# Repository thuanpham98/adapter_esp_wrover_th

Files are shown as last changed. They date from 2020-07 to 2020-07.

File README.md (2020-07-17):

# ESP-WROVER_OPEN
## Hardware

### PCB Layout

#### Dismention 
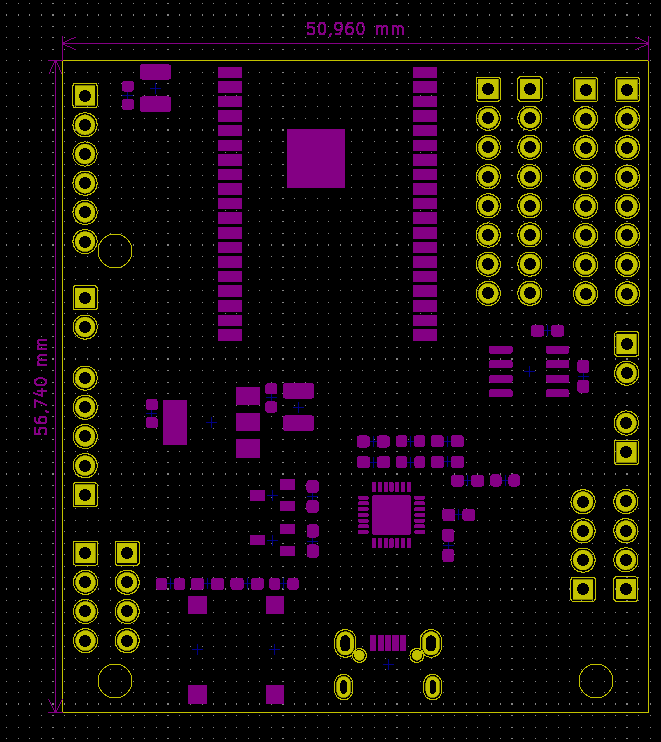
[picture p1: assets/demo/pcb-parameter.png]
pcb-parameter


#### Top side 

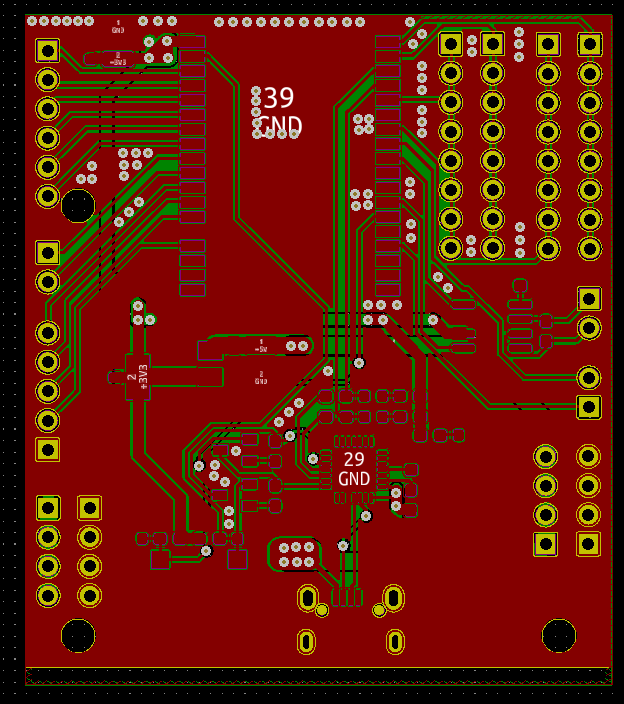
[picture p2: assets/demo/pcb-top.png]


#### Back side 

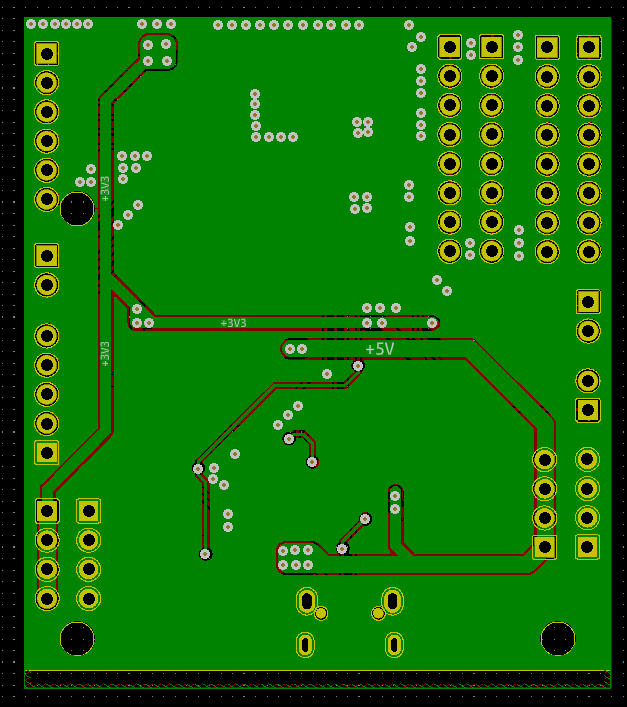
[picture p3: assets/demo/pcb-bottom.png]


### 3D

#### Top side 

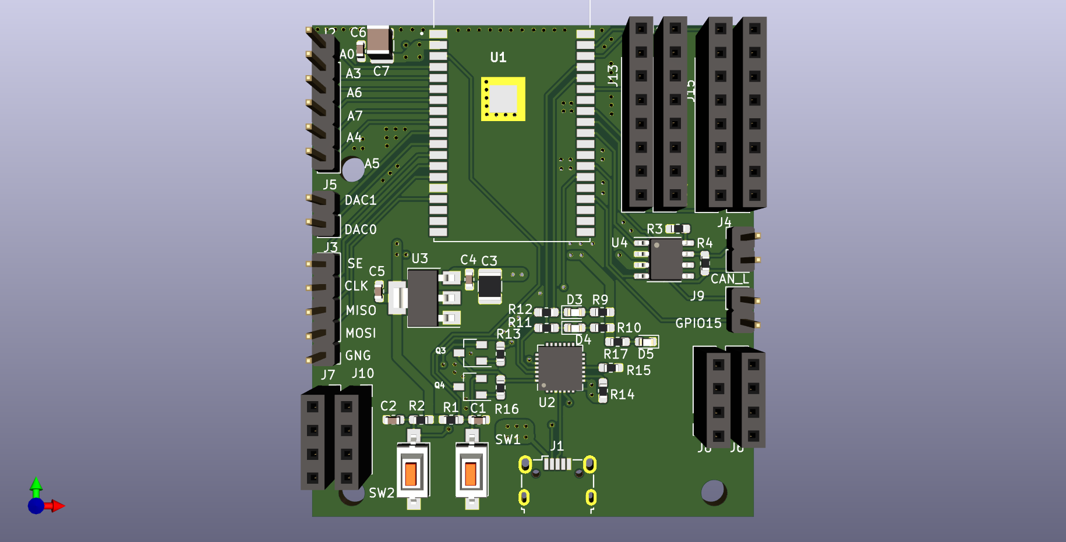
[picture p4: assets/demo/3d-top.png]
BE-AMP 3D REVIEW


#### Back side 

BE-AMP 3D REVIEW

### Gerber

# License

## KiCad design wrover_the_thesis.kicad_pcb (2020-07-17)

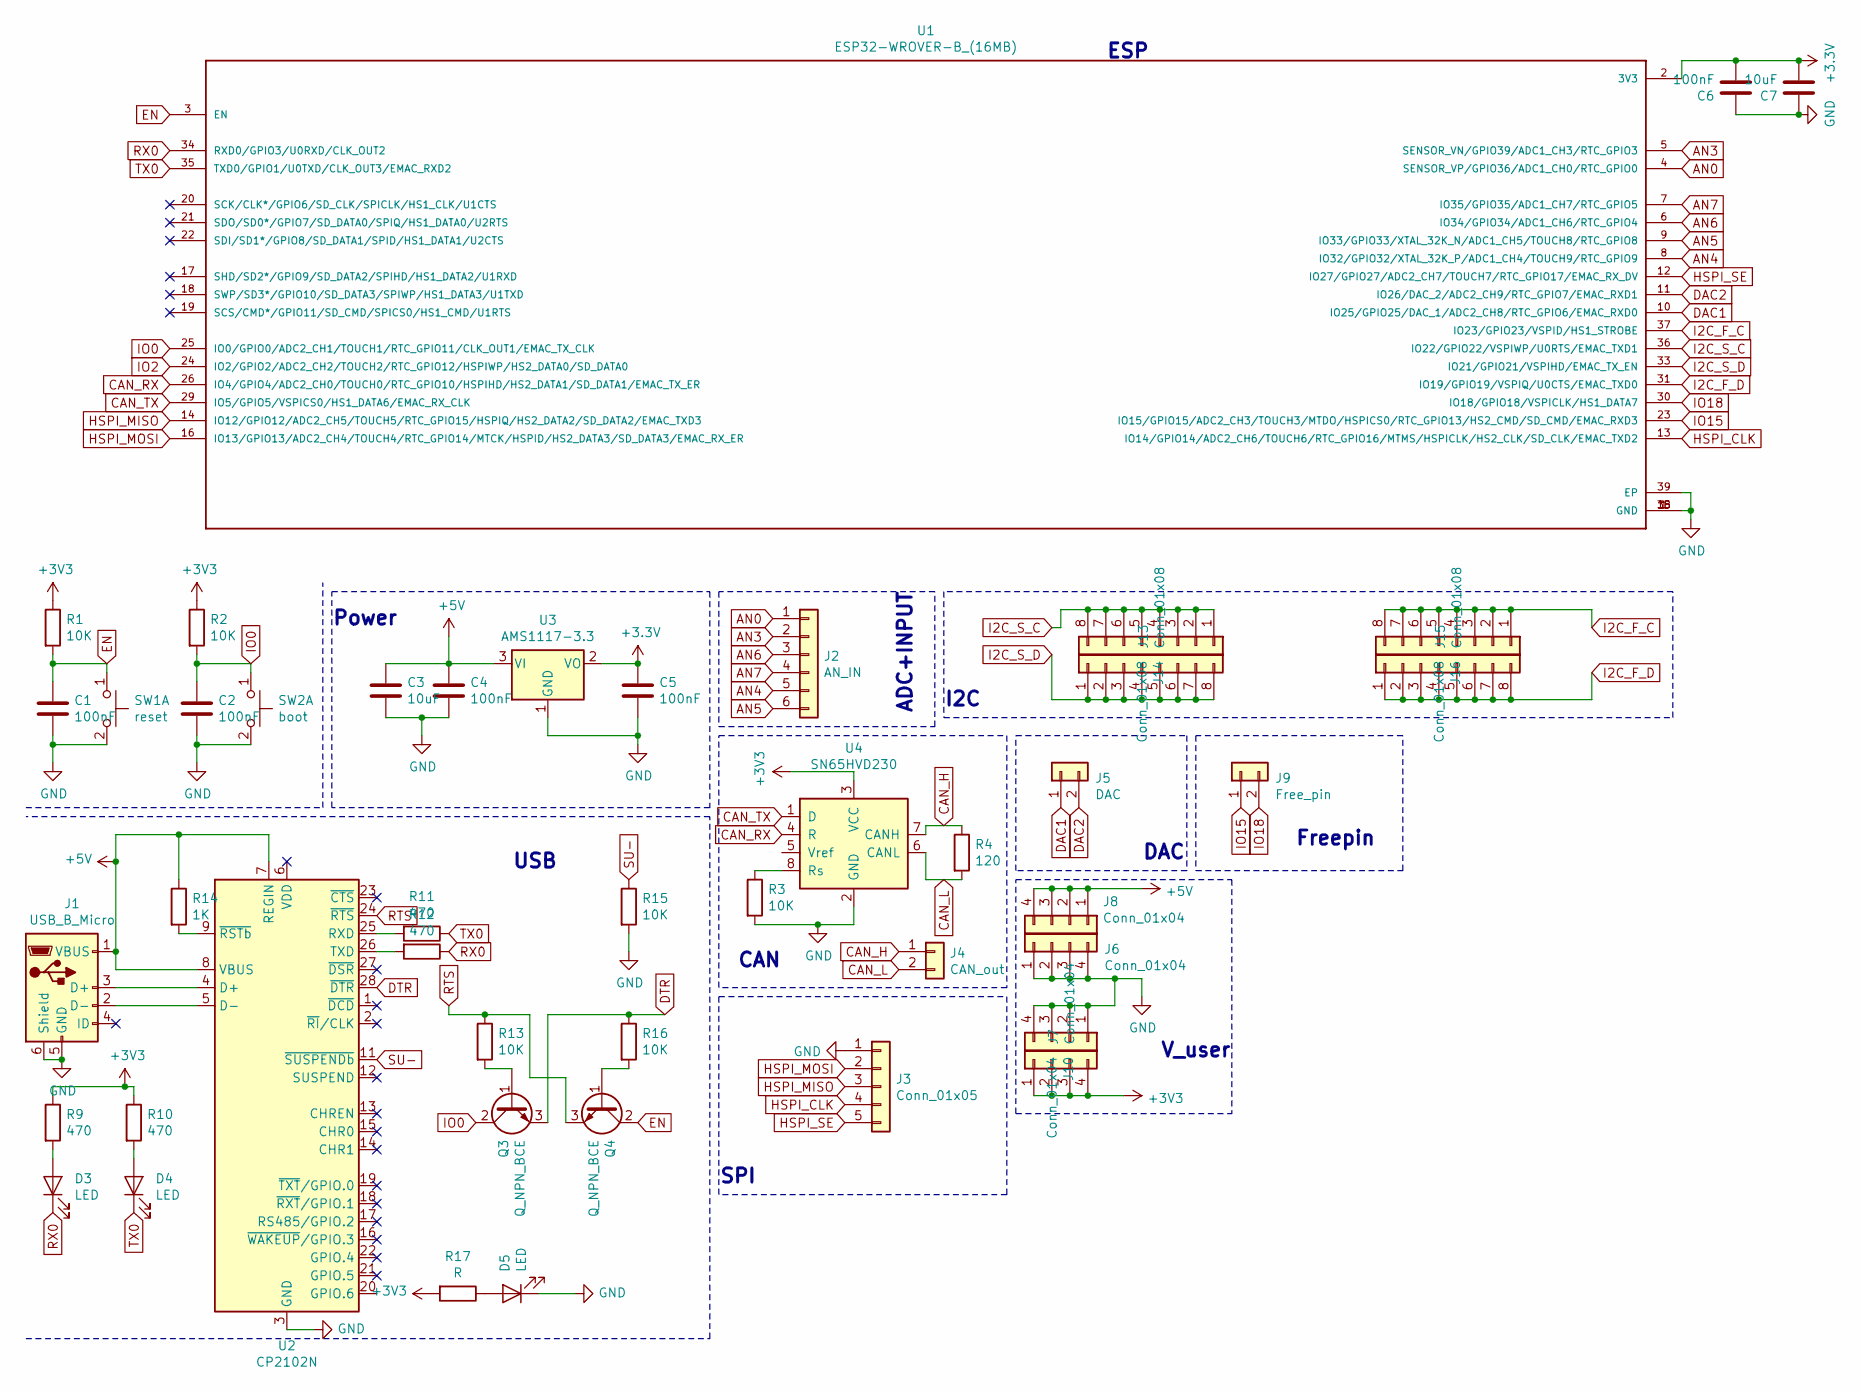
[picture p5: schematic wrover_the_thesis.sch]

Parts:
C1, C2, C4, C5, C6: 100nF; C_0603_1608Metric
C3: 10uF; R_1210_3225Metric
C7: 10uF; C_1210_3225Metric
D3, D4, D5: LED; LED_0603_1608Metric
J1: USB_B_Micro; USB_Micro-B_Wuerth_629105150521
J2: AN_IN; PinHeader_1x06_P2.54mm_Vertical
J3: Conn_01x05; PinHeader_1x05_P2.54mm_Vertical
J4: CAN_out; PinHeader_1x02_P2.54mm_Vertical
J5: DAC; PinHeader_1x02_P2.54mm_Vertical
J6, J7, J8, J10: Conn_01x04; PinSocket_1x04_P2.54mm_Vertical
J9: Free_pin; PinHeader_1x02_P2.54mm_Vertical
J13, J14, J15, J16: Conn_01x08; PinSocket_1x08_P2.54mm_Vertical
Q3, Q4: Q_NPN_BCE; SOT-23_standar
R1, R2, R3, R13, R15, R16: 10K; R_0603_1608Metric_Pad1.05x0.95mm_HandSolder
R4: 120; R_0603_1608Metric_Pad1.05x0.95mm_HandSolder
R9, R10, R11, R12: 470; R_0603_1608Metric_Pad1.05x0.95mm_HandSolder
R14: 1K; R_0603_1608Metric_Pad1.05x0.95mm_HandSolder
R17: R; R_0603_1608Metric_Pad1.05x0.95mm_HandSolder
SW1: reset; SW_SPST_CK_RS282G05A3
SW2: boot; SW_SPST_CK_RS282G05A3
U1: ESP32-WROVER-B_(16MB); XCVR_ESP32-WROVER-B_(16MB)
U2: CP2102N; QFN-28-1EP_5x5mm_P0.5mm_EP3.35x3.35mm
U3: AMS1117-3.3; SOT-223-3_TabPin2
U4: SN65HVD230; SOIC-8_3.9x4.9mm_P1.27mm

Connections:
+5V: C3.1, C4.1, J1.1 (VBUS), J8.1, J8.2, J8.3, J8.4, R14.1, U2.7 (REGIN), U2.8 (VBUS), U3.3 (VI)
AN0: J2.1, U1.4 (SENSOR_VP/GPIO36/ADC1_CH0/RTC_GPIO0)
AN3: J2.2, U1.5 (SENSOR_VN/GPIO39/ADC1_CH3/RTC_GPIO3)
AN4: J2.5, U1.8 (IO32/GPIO32/XTAL_32K_P/ADC1_CH4/TOUCH9/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)
AN5: J2.6, U1.9 (IO33/GPIO33/XTAL_32K_N/ADC1_CH5/TOUCH8/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)
AN6: J2.3, U1.6 (IO34/GPIO34/ADC1_CH6/RTC_GPIO4)
AN7: J2.4, U1.7 (IO35/GPIO35/ADC1_CH7/RTC_GPIO5)
CAN_H: J4.1, R4.1, U4.7 (CANH)
CAN_L: J4.2, R4.2, U4.6 (CANL)
CAN_RX: U1.26 (IO4/GPIO4/ADC2_CH0/TOUCH0/RTC_GPIO10/HS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), U4.4 (R)
CAN_TX: U1.29 (IO5/GPIO5/VSPICS0/HS1_DATA6/EMAC_RX_CLK), U4.1 (D)
DAC1: J5.1, U1.10 (IO25/GPIO25/DAC_1/ADC2_CH8/RTC_GPIO6/EM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)
DAC2: J5.2, U1.11 (IO26/DAC_2/ADC2_CH9/RTC_GPIO7/EMAC_RXD1)
DTR: Q3.3 (E), R16.1, U2.28 (~DTR)
EN: C1.1, Q4.2 (C), R1.2, SW1.1 (C), U1.3 (EN)
GND: C1.2, C2.2, C3.2, C4.2, C5.2, C6.1, C7.1, D5.1 (K), J1.5 (GND), J1.6 (Shield), J3.1, J6.1, J6.2, J6.3, J6.4, J10.1, J10.2, J10.3, J10.4, R3.2, R15.2, SW1.2 (D), SW2.2 (D), U1.1 (GND), U1.15 (GND), U1.38 (GND), U1.39 (EP), U2.3 (GND), U2.29 (GND), U3.1 (GND), U4.2 (GND)
HSPI_CLK: J3.4, U1.13 (IO14/GPIO14/ADC2_CH6/TOUCH6/RTC_GPIO16/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)
HSPI_MISO: J3.3, U1.14 (IO12/GPIO12/ADC2_CH5/TOUCH5/RTC_GPIO15/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)
HSPI_MOSI: J3.2, U1.16 (IO13/GPIO13/ADC2_CH4/TOUCH4/RTC_GPIO14/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)
HSPI_SE: J3.5, U1.12 (IO27/GPIO27/ADC2_CH7/TOUCH7/RTC_GPIO17/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)
I2C_F_C: J16.1, J16.2, J16.3, J16.4, J16.5, J16.6, J16.7, J16.8, U1.37 (IO23/GPIO23/VSPID/HS1_STROBE)
I2C_F_D: J15.1, J15.2, J15.3, J15.4, J15.5, J15.6, J15.7, J15.8, U1.31 (IO19/GPIO19/VSPIQ/U0CTS/EMAC_TXD0)
I2C_S_C: J14.1, J14.2, J14.3, J14.4, J14.5, J14.6, J14.7, J14.8, U1.36 (IO22/GPIO22/VSPIWP/U0RTS/EMAC_TXD1)
I2C_S_D: J13.1, J13.2, J13.3, J13.4, J13.5, J13.6, J13.7, J13.8, U1.33 (IO21/GPIO21/VSPIHD/EMAC_TX_EN)
IO0: C2.1, Q3.2 (C), R2.2, SW2.1 (C), U1.25 (IO0/GPIO0/ADC2_CH1/TOUCH1/RTC_GPIO11/CL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)
IO15: J9.1, U1.23 (IO15/GPIO15/ADC2_CH3/TOUCH3/MTDO/HSPICS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)
IO18: J9.2, U1.30 (IO18/GPIO18/VSPICLK/HS1_DATA7)
unnamed: D3.2 (A), R9.2
unnamed: D4.2 (A), R10.2
unnamed: D5.2 (A), R17.1
unnamed: J1.2 (D-), U2.5 (D-)
unnamed: J1.3 (D+), U2.4 (D+)
unnamed: Q3.1 (B), R13.2
unnamed: Q4.1 (B), R16.2
unnamed: R3.1, U4.8 (Rs)
unnamed: R11.2, U2.25 (RXD)
unnamed: R12.2, U2.26 (TXD)
unnamed: R14.2, U2.9 (~RSTb)
RTS: Q4.3 (E), R13.1, U2.24 (~RTS)
RX0: D3.1 (K), R12.1, U1.34 (RXD0/GPIO3/U0RXD/CLK_OUT2)
SU-: R15.1, U2.11 (~SUSPENDb)
TX0: D4.1 (K), R11.1, U1.35 (TXD0/GPIO1/U0TXD/CLK_OUT3/EMAC_RXD2)

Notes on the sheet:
Power
ESP
USB
ADC+INPUT
CAN
SPI
I2C
DAC
Freepin
V_user

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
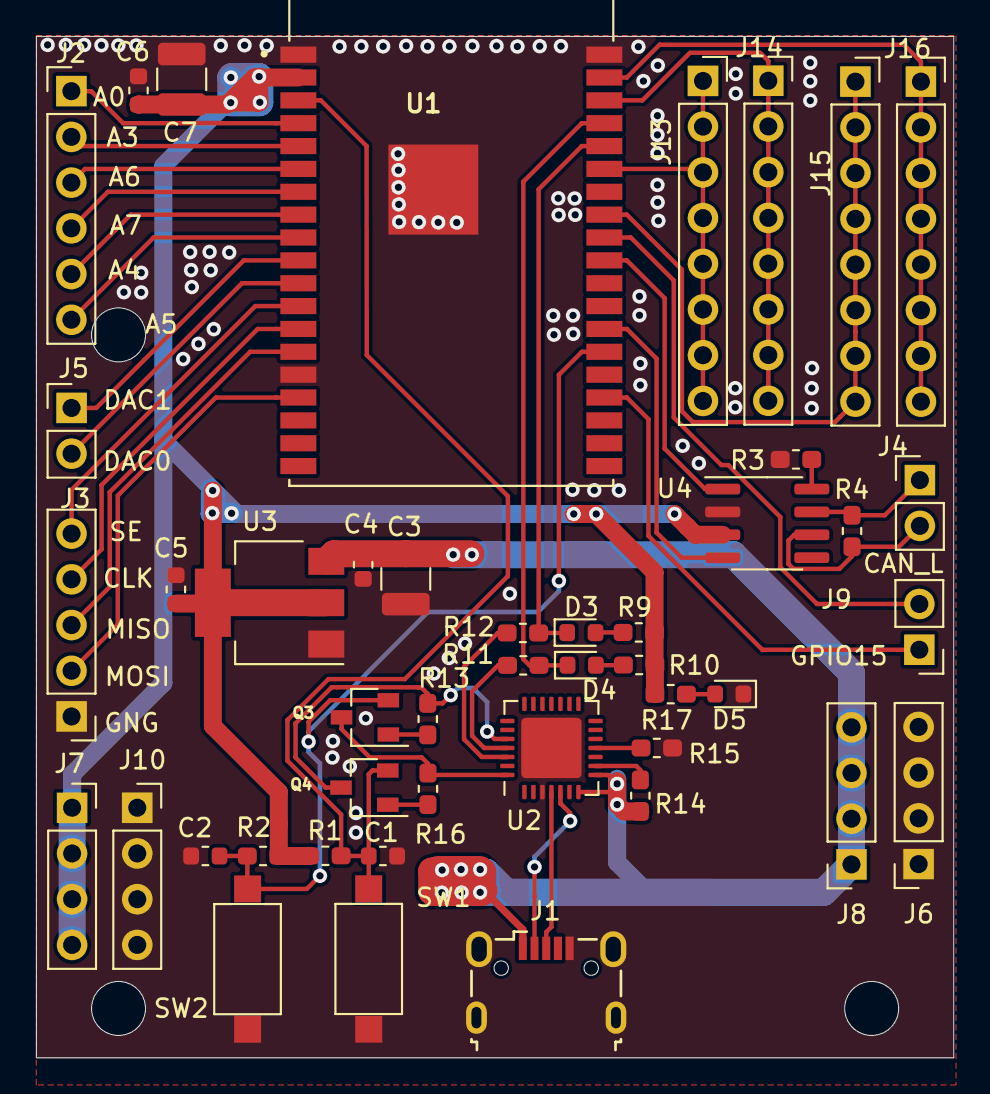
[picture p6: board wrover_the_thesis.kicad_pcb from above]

Board: 2 copper layers, 51.0 x 56.7 mm, 45 parts (0 on the bottom side), 43 nets.
